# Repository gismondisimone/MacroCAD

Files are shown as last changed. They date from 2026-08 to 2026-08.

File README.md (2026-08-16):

# MacroCAD - More Numbers Is ALWAYS Better

### A Tiny, Industrial Look, Feature-Packed Macropad for Maximum Efficiency

*(or just a cool number-pad).*

---

## Renders

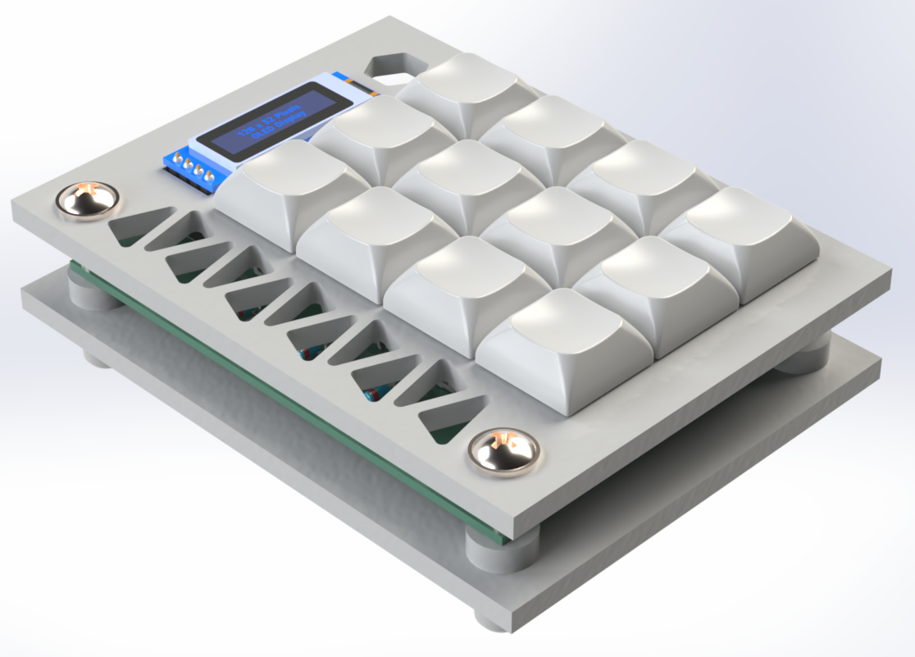
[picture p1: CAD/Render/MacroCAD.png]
MacroCAD Render

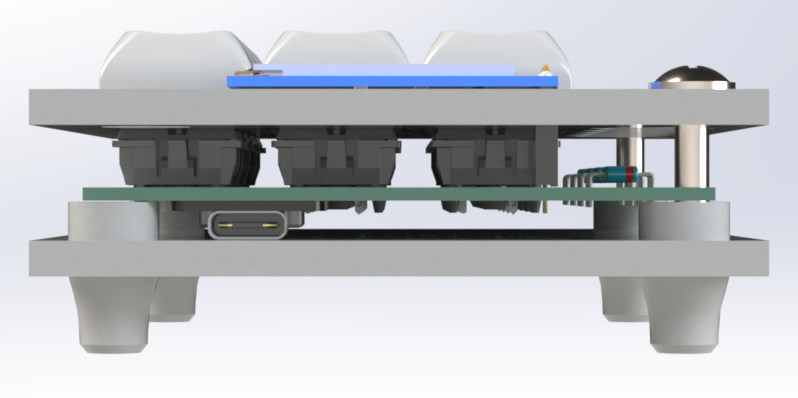
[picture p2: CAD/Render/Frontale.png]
MacroCAD Frontale Render

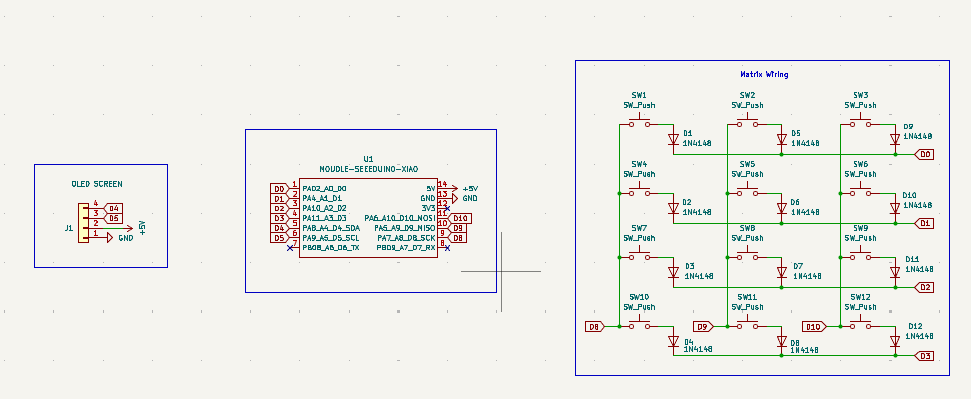
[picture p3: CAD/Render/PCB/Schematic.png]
MacroCAD Schematic

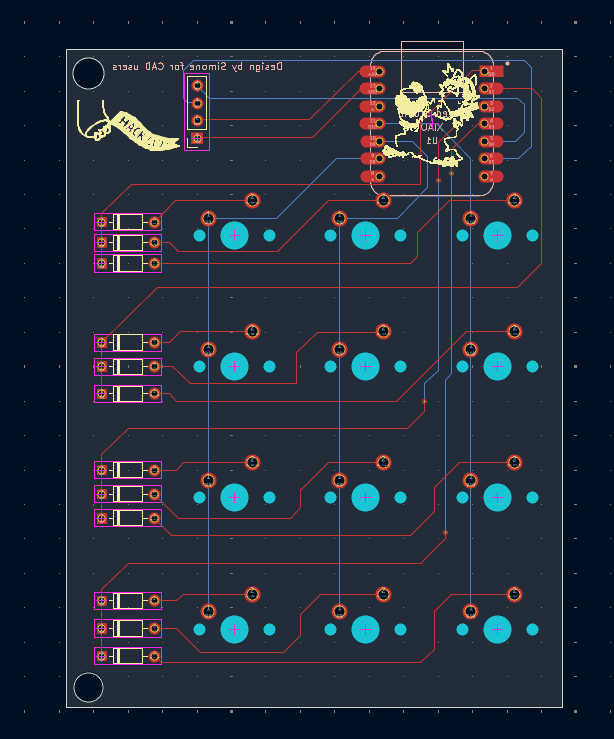
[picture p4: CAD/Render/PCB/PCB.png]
MacroCAD PCB


---
## BOM
All the bits and pieces needed can be found **[here](/BOM.md)**.

---

## What is This?
It's a **custom macropad** built with the **Seeed Studio XIAO RP2040**, **QMK firmware**. It's designed by a CAD user for CAD users. The design is as cool as fragile.

### Features:
- **3x4 Matrix** - Just numbers and a dot key and enter key.
- **OLED Display** - It's a cool add-on though I will update its functions in the future.
- **QMK Firmware** - Open-source, because we like freedom.

---

## How It Works:
This macropad runs **QMK**, which means you get:
- **Custom Keymaps** - Map macros, media keys, or even full-blown scripts.
- **Dynamic Layers** - More functions per button? Yes, please.
- **Display Support** - A cat that reminds you to work on your project? An integration with Hackatime that shows up your hours spent on designing.

---

## Default Keymap:
*(Change it if you want, you could delete the enter key and put a shortcut for your CAD software).*

### **3x4 Button Layout:**
|Row  | Key 1 | key 2 | Key 3 |
|-----|---|---|---|
|**1**| 7 | 8 | 9 |
|**2**| 4 | 5 | 6 |
|**3**| 1 | 2 | 3 |
|**4**| 0 | . |  ent  |

---

## How to Build It:

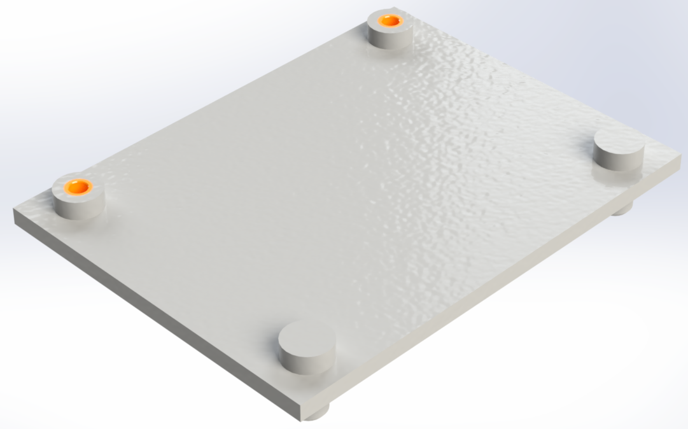
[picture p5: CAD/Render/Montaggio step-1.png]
MacroCAD Step-1

**Step 1** - Put the inserts in the holes on the bottom part.

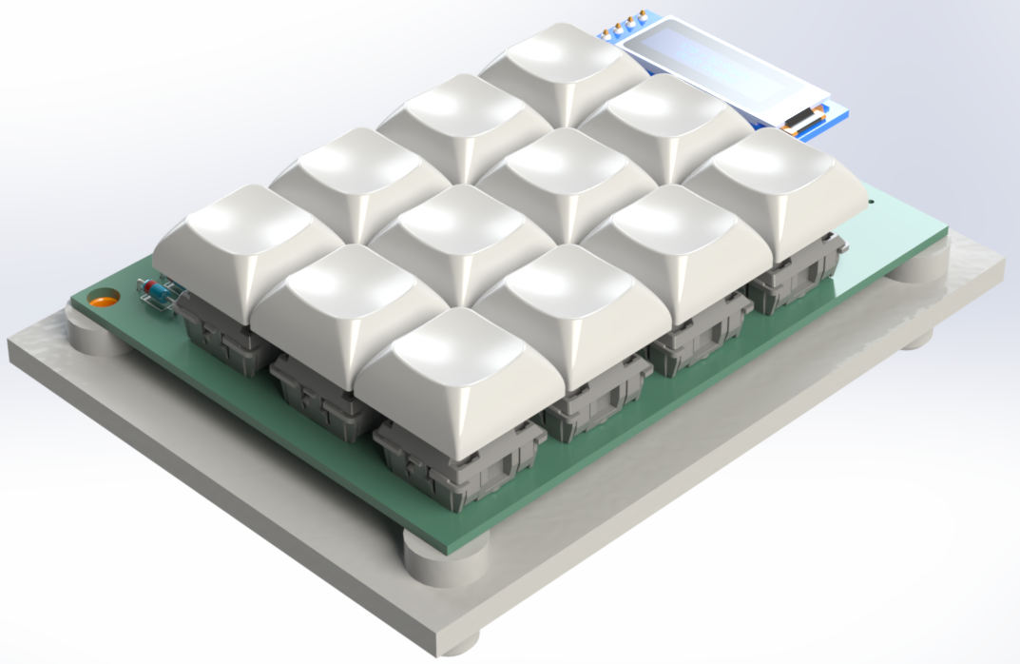
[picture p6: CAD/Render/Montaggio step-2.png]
MacroCAD Step-2

**Step 2** - Align holes on the PCB to the holes on the bottom part.

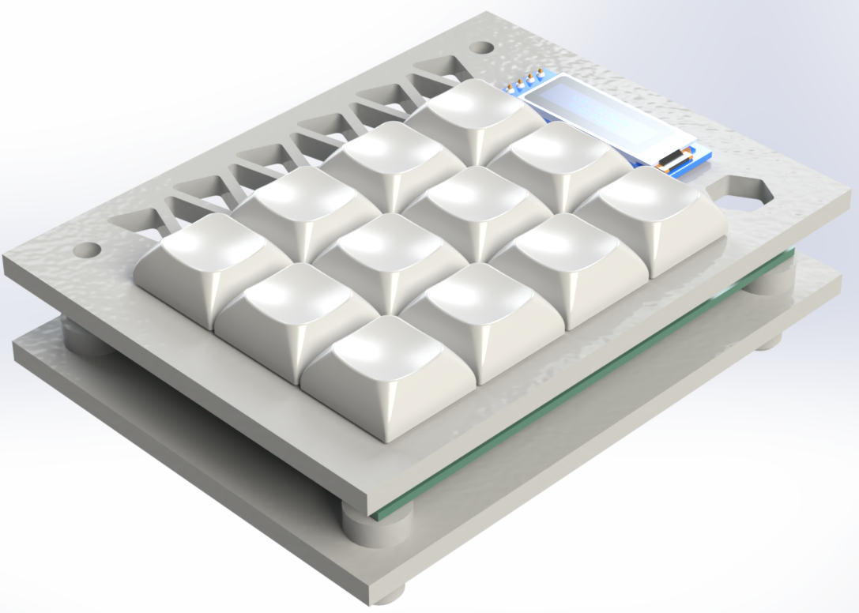
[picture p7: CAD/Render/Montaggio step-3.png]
MacroCAD Step-3

**Step 3** - Align holes on the top part to the holes on the PCB.

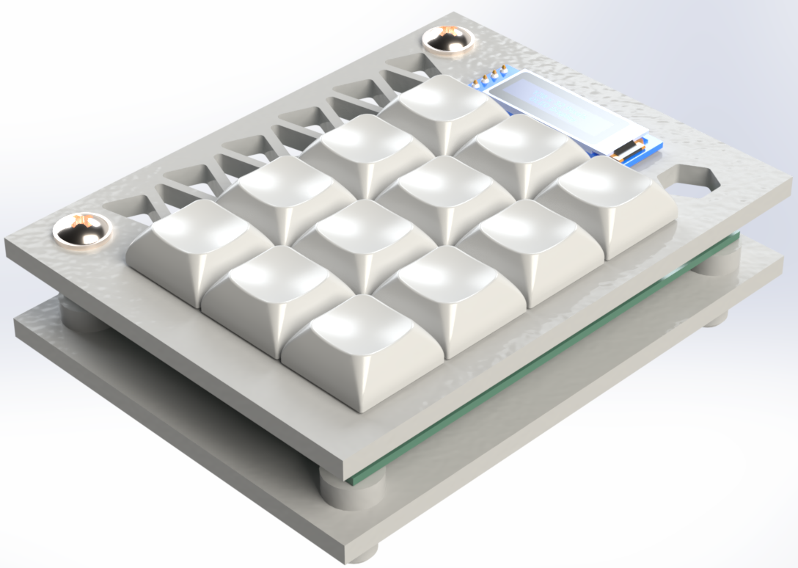
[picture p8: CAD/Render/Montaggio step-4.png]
MacroCAD Step-4

**Step 4** - Put two M4x25 screws in the holes.

---

## Why?
I built this macropad for [Hackpad](https://hackpad.hackclub.com/)-an awesome Hack Club YSWS project. With the (hopeful) funding provided by the project, I wanted to create something that's as practical as it is professional. Whether you're designing your favorite projects, this macropad is my way of saying:

#### why settle for ordinary when you can hack something extraordinary?

## The Biggest Challenge:
It's my second time designing a PCB, I'm slowly improving.

---

## Future Plans (Maybe):
- Encoder?
- Bluetooth support? (Would need a battery)
- Improving the design with aluminum frame, LEDS?

---

## Contribute  
Want to make it better? Open a PR, suggest a feature, or just yell at me on GitHub.

---

## Disclaimer  
This project is 100% free, open-source, and powered by **vibes**. If it breaks, explodes, or opens a black hole, **that's on you.**

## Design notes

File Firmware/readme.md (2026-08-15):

# macrocad

MacroCAD is a KeyPad Design by a CAD user for CAD users

* Keyboard Maintainer: [Simone](https://github.com/gismondisimone)
* Hardware:** Seeed XIAO RP2040
* Hardware Availability: https://github.com/gismondisimone/MacroCAD

## Bootloader

Per entrare in modalità bootloader, tieni premuto il tasto BOOT, premi e rilascia RESET, quindi rilascia BOOT.

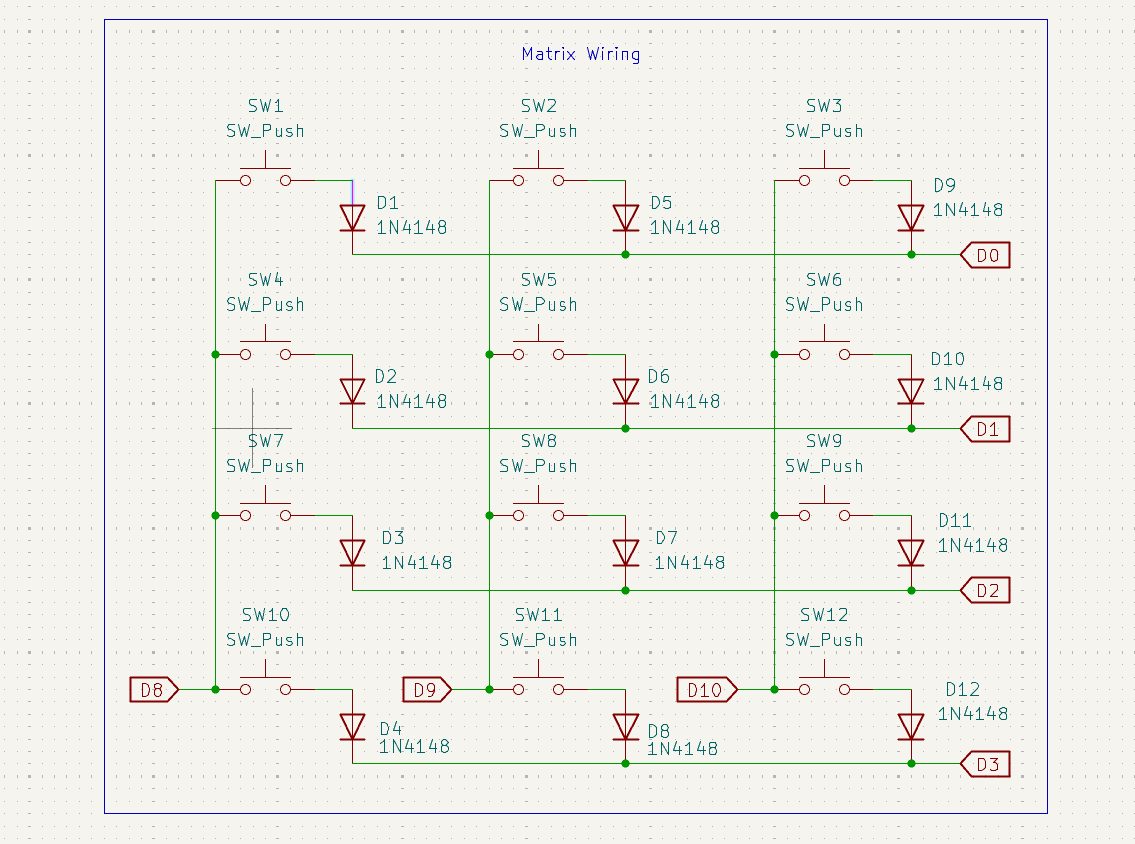
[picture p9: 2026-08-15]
CAD/Render/PCB/Matrix.png

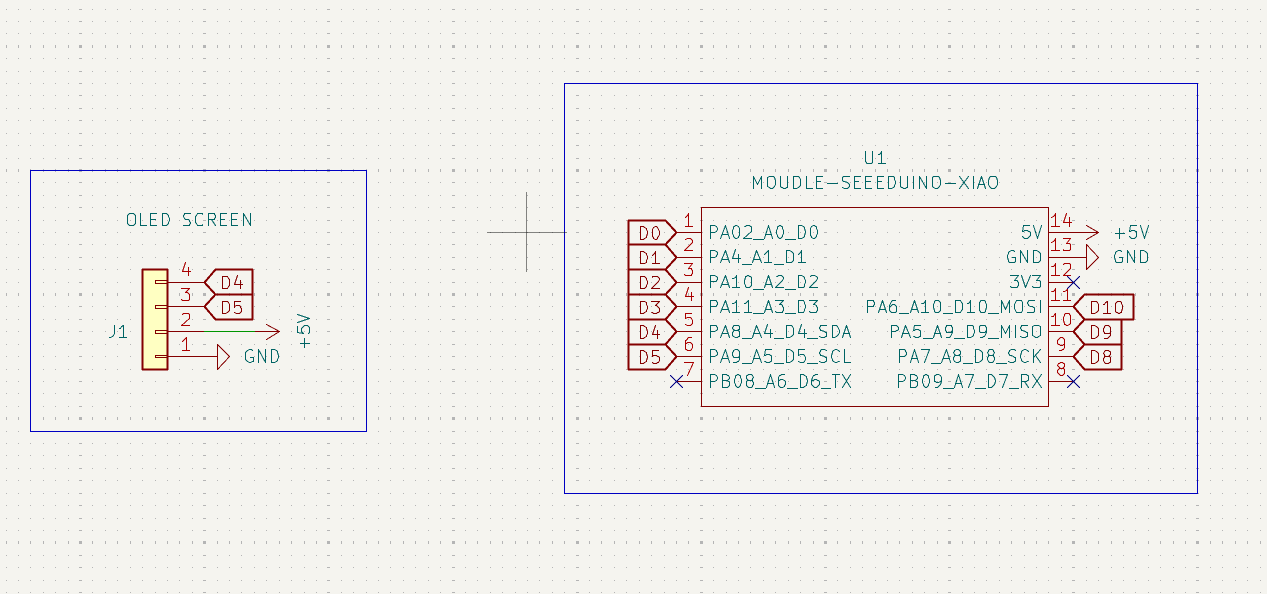
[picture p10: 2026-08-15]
CAD/Render/PCB/XIAO-OLED.png

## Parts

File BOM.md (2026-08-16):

# MacroCAD - Bill of Materials

Welcome to the **Bill of Materials (BOM)** - the sacred scroll of **everything** needed for my MacroCAD.

*(Because nothing's worse than realizing you forgot the screws after your parts arrive.)* 

| **Component** | **Qty** |
|---|---|
| **XIAO RP2040** | 1 |
| **Cherry MX Switches** | 12 |
| **PCB** | 1 |
| **Diodes (1N4148)** | 12 |
| **0.91 inch OLED display**| 1 |
| **M4x25 Bolt** | 2 |
| **M4 Insert** | 2 |

Others:

| **Component** | **Qty** |
|---|---|
| **1U Keycaps** | 12 |
| **KMK Firmware** | 1 |
| **PCB** | 1 |
| [**Case Top.stl**](/Production/top%20v.2.STEP) | 1 |
| [**Case Bottom.stl**](/Production/Base.STEP) | 1 |

### Notes:
I don't need to have parts printed, I'm also buying the bolts and insert.

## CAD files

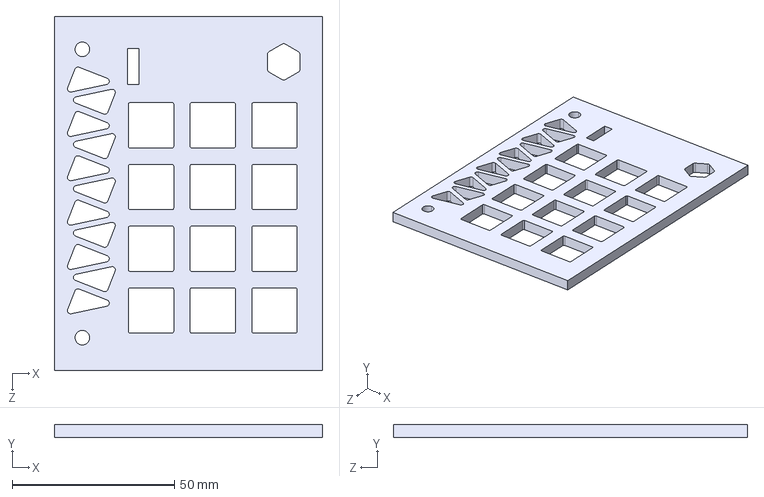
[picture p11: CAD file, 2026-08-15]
Production/top v.2.STEP
82.8 x 4.00 x 109.2 mm

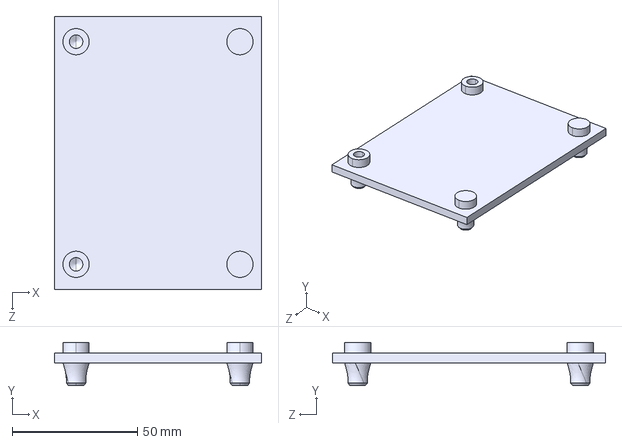
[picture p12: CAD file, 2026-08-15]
Production/Base.STEP
82.8 x 17.3 x 109.2 mm

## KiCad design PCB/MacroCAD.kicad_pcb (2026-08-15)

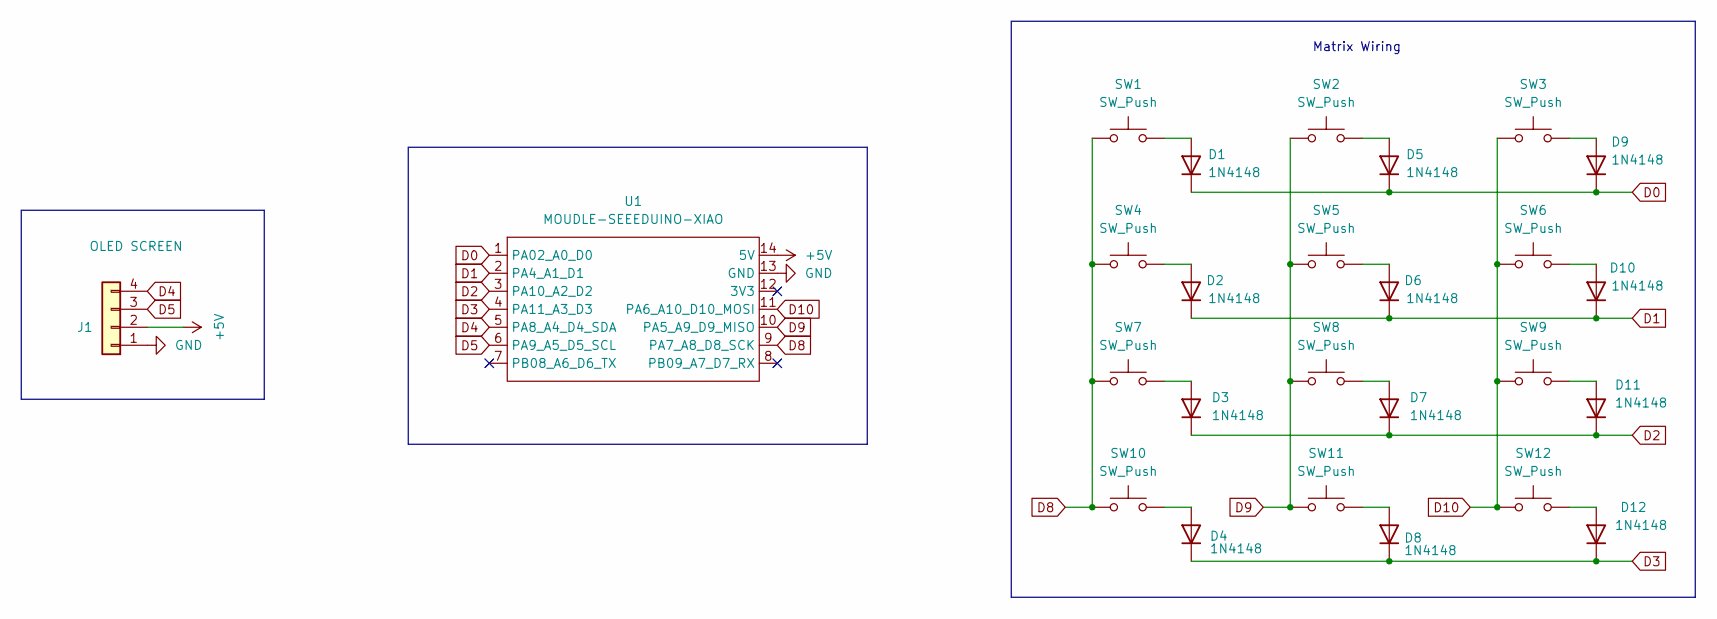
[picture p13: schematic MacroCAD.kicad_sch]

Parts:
D1, D2, D3, D4, D5, D6, D7, D8, D9, D10, D11, D12: 1N4148; D_DO-35_SOD27_P7.62mm_Horizontal
J1: OLED SCREEN; PinSocket_1x04_P2.54mm_Vertical
SW1, SW2, SW3, SW4, SW5, SW6, SW7, SW8, SW9, SW10, SW11, SW12: SW_Push; MX-Solderable-1.25U
U1: MOUDLE-SEEEDUINO-XIAO; XIAO-Generic-Hybrid-14P-2.54-21X17.8MM

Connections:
+5V: J1.2, U1.14 (5V)
D0: D1.1 (K), D5.1 (K), D9.1 (K), U1.1 (PA02_A0_D0)
D1: D2.1 (K), D6.1 (K), D10.1 (K), U1.2 (PA4_A1_D1)
D2: D3.1 (K), D7.1 (K), D11.1 (K), U1.3 (PA10_A2_D2)
D3: D4.1 (K), D8.1 (K), D12.1 (K), U1.4 (PA11_A3_D3)
D4: J1.4, U1.5 (PA8_A4_D4_SDA)
D5: J1.3, U1.6 (PA9_A5_D5_SCL)
D8: SW1.1, SW4.1, SW7.1, SW10.1, U1.9 (PA7_A8_D8_SCK)
D9: SW2.1, SW5.1, SW8.1, SW11.1, U1.10 (PA5_A9_D9_MISO)
D10: SW3.1, SW6.1, SW9.1, SW12.1, U1.11 (PA6_A10_D10_MOSI)
GND: J1.1, U1.13 (GND)
unnamed: D1.2 (A), SW1.2
unnamed: D2.2 (A), SW4.2
unnamed: D3.2 (A), SW7.2
unnamed: D4.2 (A), SW10.2
unnamed: D5.2 (A), SW2.2
unnamed: D6.2 (A), SW5.2
unnamed: D7.2 (A), SW8.2
unnamed: D8.2 (A), SW11.2
unnamed: D9.2 (A), SW3.2
unnamed: D10.2 (A), SW6.2
unnamed: D11.2 (A), SW9.2
unnamed: D12.2 (A), SW12.2

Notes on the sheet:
Matrix Wiring

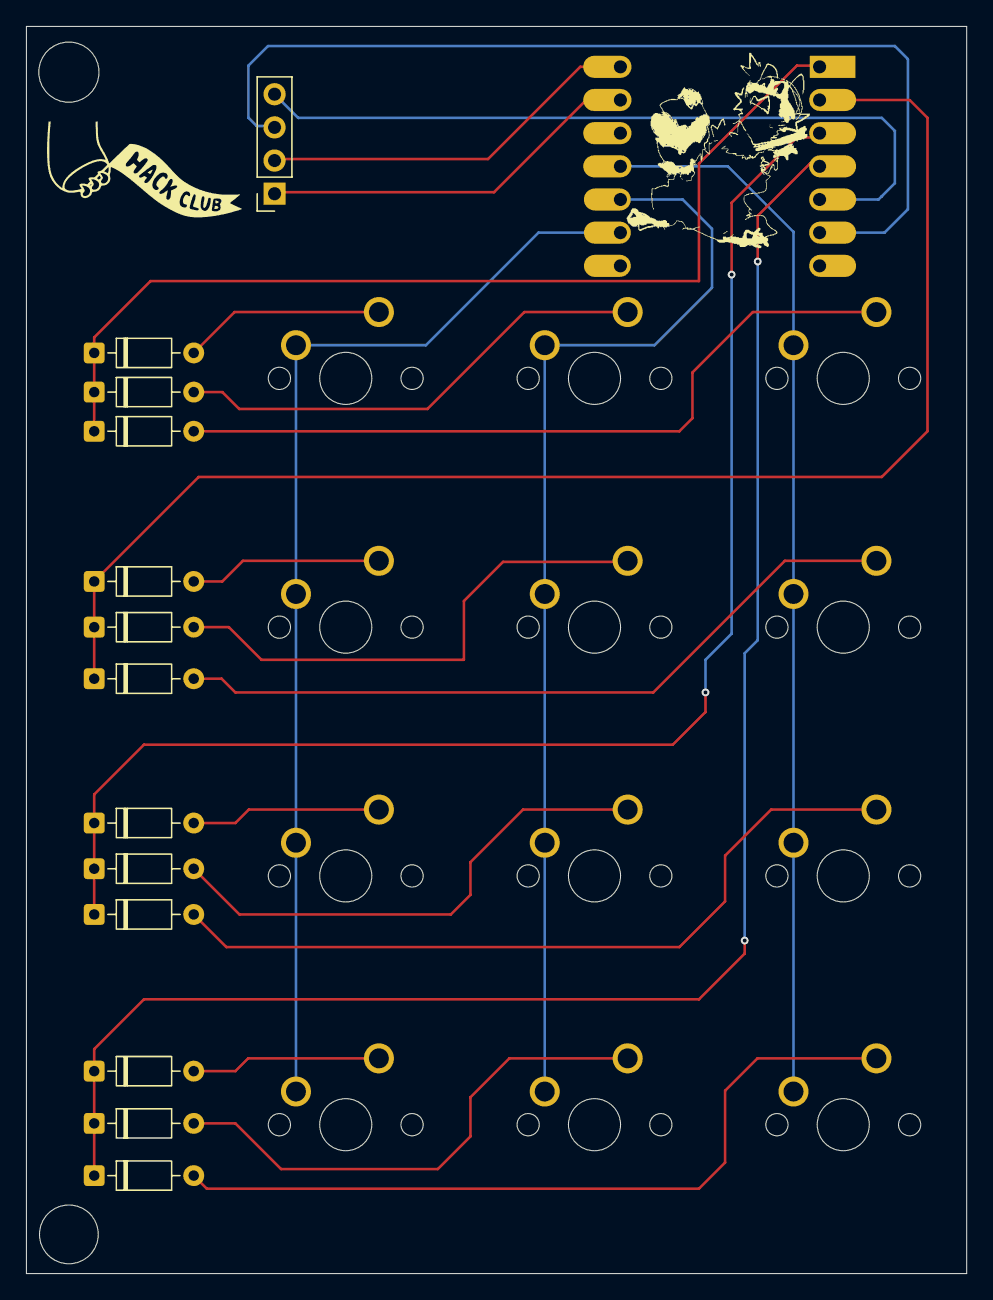
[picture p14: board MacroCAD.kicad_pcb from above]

Board: 2 copper layers, 72.0 x 95.5 mm, 27 parts (1 on the bottom side), 23 nets.

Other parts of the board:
G: LOGO

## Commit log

2026-08-15 Inizializzazione completa MacroCAD
    [Base.SLDPRT, Base.STEP, Inserti M4.SLDPRT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]
2026-08-15 Applicato nuovo .gitignore e rimossi file ignorati
    [Base.SLDPRT, Inserti M4.SLDPRT, MX.SLDASM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]
2026-08-15 PCB's final toutch
    [MacroCAD.kicad_pcb, MacroCAD.kicad_sch]
2026-08-16 Prova BOM
2026-08-16 Modifica README e BOM
2026-08-16 README and BOM
